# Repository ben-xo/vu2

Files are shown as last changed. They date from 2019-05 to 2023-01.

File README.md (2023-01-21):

Sound Reactive Lights (visualiser!)
===================================

This is a self indulgent project by Ben XO https://github.com/ben-xo

The idea is that you feed line level audio into a pin on an arduino, and you get pretty lights out on a strip of Neopixels (WS2812 or compatible).

License
-------

Copyright Ben XO https://github.com/ben-xo All rights reserved.

THIS PROJECT IS NOT OPEN SOURCE. Whilst I have put the source code on GitHub, no part of this project is currently released under any open source license.

I reserve all rights and the right to change this license in future.

What does it look like?
=======================

Kinda like this https://www.instagram.com/p/Bt-8dVqlZSi/ or this https://www.instagram.com/p/Bt-8dVqlZSi/

Features
========

* Works from line-in
* Interrupt driven audio sampling - even with WS2812s (requires a slightly modified FastLED library at https://github.com/ben-xo/FastLED)
* A solid 180 frame per second with 60 WS2812s (or 125fps with 100 WS2812s) with no slow frames or dropped samples
* Beat detection and tempo estimation in realtime. Yep! All on a single Arduino
* 8 cool sound-reactive visualisers. These have been endlessly tinkered with so that they look okay at a range of input volumes and aren't TOO jarring when they change
* Automatic mode changing after a certain number of beats
* Effects work well for a range of music from house and techno to drum & bass
* Visualisers cope with things like DC Offset on the line-in
* push button to change modes
* Status LEDs driven using interrupt driven PWM (so no need for resistors on the status LEDs)
* Screensaver when the audio goes quiet. Because why not!
* Nice rainbow when you turn it on

How to use
==========

Circuit
-------

First of all this should go without saying but LEAVE THE POWER DISCONNECTED until you're ready

You should load up config.h as that's where the pins are assigned - and double check these instructions against it.

Also, I refuse to draw an ASCII diagram so you'll have to interpret my words.

Audio Input
-----------

The audio input stage expects "0" to be at around 2.5v (i.e the mid range of the analog input).

Minimum would be something like:
* ground of audio connected to ground of arduino
* signal (left or right audio channel) connected to A0 through a 3.3uF electrolytic cap
* signal connected to ground via a 103 cap
* signal connected to ground and +5v through 100k resistors (to create a potential divider to get the signal to sit at 2.5v)

That's it.

Output LEDs
-----------

* connect 4 LEDs from D8, D9, D10, and D11 to ground A, B, G and F on a 7-segment. These will show the mode and other things.
  (if you don't have a 7-seg, any LEDs will do). No resistors needed

  Note that quite a lot of stuff is configurable in the config.h BUT THESE ARE NOT because we rely on them being in the half of PORTB.

* connect 2 LEDs from A1 and A2 to ground. These flash in time for the beats. I would connect them to the 7 seg in 2 of the unused positions
  (I use the decimal point, and the low bar.) 

* Configure to other pins if you want, avoid PORTB

Mode Button
-----------

* Pull D7 to ground through a 10k resistor. (if you don't and it floats the mode will go haywire)
* Connect a push button from D7 to pull up to 5v. That's it
* Configure to another pin if you want, but avoid PORTB

LED light strip
---------------

Connect some WS2812s or whatever through a 330 resistor to D6, in "the usual way".

Notes on Power
--------------

Powering an Arduino and lights safely / effectively is a dark art.

Choose a PSU you trust. For 1 Arduino and 2x strips of 60 NeoPixels you probably don't need more than a 2A supply because we're never going to be turning all the lights on full white and leaving them on full white. See https://learn.adafruit.com/adafruit-neopixel-uberguide/powering-neopixels for TMI about how to calculate power usage.

You can wire a 5v supply directly to the 5v pins on the Arduino, but if you do that, you bypass the fuses on the Arduino and if your PSU turns out to be untrustworthy you may end up needing to buy a new Arduino.

You can power the Arduino and lights separately, but if you do, you must connect the GND pins together.

You'll know if you don't have enough power because the thing will keep rebooting (you get a nice rainbow every time it starts up)

Debug monitoring
----------------

If you wanna watch the frame rate (and time taken to do various stages in the main loop) on an oscilloscope, you can hook an oscilloscope to pins D2 and D3. You may need to add a resistor to pull them to GND, or 5v… or you might not need to do either!

If it's working correctly when you zoom in you should see 150Hz on D3 and "other stuff" on D2 which shows phases of the draw and render. (If you want to see the sample rate specifically, you'll need to comment out the usages of DEBUG_SAMPLE_RATE_PIN and uncomment the ones in sampler.h)

Software
--------

***Very important: you need to build against a custom branch of FastLED!***

1) Set up Arduino Studio (or arduino-cli)
2) Install FastLED lib
3) REPLACE FastLED lib with the version from https://github.com/ben-xo/FastLED . My version has modifications to enable interrupts in certain places in order to not drop samples.
4) Make sure the modified FastLED is checked out to the branch `feature/ben-xo-integration-branch`
5) Load vu3.ino into Arduino Studio
6) edit config.h . set your strip length. maybe comment out the DEBUG defines if i left them uncommented
7) program the arduino over USB. (or use ./build-and-upload.sh if you went with arduino-cli)

*N.B* You may want to upgrade avr-gcc to version 11. Setting this up is out of scope of the README. 

Rough instructions for that:
* `brew install arduino-cli`
* `brew tap osx-cross/avr`
* `brew install avr-gcc@11`
* `brew link avr-gcc@11`
* modify `~/Library/Arduino15/packages/arduino/hardware/avr/1.8.3/platform.txt` - change `compiler.path` to `/usr/local/bin/`
* use `./build-and-upload.sh` instead of Arduio Studio to program the chip

Finally
-------

Plug the audio in. Plug the power in. Adjust the volume...

Push button to change modes.
Long press to reset to auto change.
Long long press to reboot.
Double click and triple click get you to an animated test mode and a static test mode. (I think)

There is a screensaver which kicks in after 15 seconds silence, but when there's a signal it is back to VU. You might need to adjust the levels low or high! Sensitivity CAN be adjusted with care in sampler.cpp (adjust "scale" in sampler.cpp), or with resistors etc.

Tips
====

Mac owners can make open Audio MIDI Setup to create a virtual soundcard that combines both the speakers AND the line-out, so that you can play audio out loud AND into the lights simultaneously. Neat trick

Enhancements
============

* You can attach LEDs (output, LED to GND) to the LED pins mentioned in config.h. They will show a binary of which mode is currently in effect. (They're even properly PWM'd so you don't need to attach resistors, like the lazy builder you always wanted to be!)
* if you hold down the button at start up it will enter test mode and the LEDs will be a simple level meter so you can test it before attaching. the Neopixel strip
* The output from the lights pin can drive two strips with the same data so you could put them back to back to make a VU twice as long reflected in the middle!

About The Software
==================

Whilst this project has evolved (slowly) from some sketches I found online, the current code is entirely my own work.

How It Works
------------

This is "what can I squeeze out of an Arduino" project the architecture is quite Arduino specific and heavily timer interrupt driven.

The main loop does does the following:
* processes all samples queued up in the sample buffer to calculate a rolling VU, DC offset and beat detection filter
* stores sample-accurate "beat" information, and recalculates the estimates tempo (which looks a lot better for drum & bass than just the kick detection on its own)
* renders a frame of visualiser
* outputs the LEDs using FastLED

Meanwhile, there are very fast interrupt handlers for sampling the audio, doing PWM on the status LEDs, and maintaining an accurate FPS.

Want to work on it?
-------------------

Yeah! You do! I have no idea what to tell you, ask me questions on Twitter @benxo I have loads of ideas and none of them are important.

Thanks for coming to my TED talk

History
=======

* Worked on it throughout 2017 to 2022
* Made it public in a fit of GitHub and Twitter dopamine-seeking on 11th June 2020
* Made it all-in-one with no second arduino required for beat detect and very fast 180fps Jan 2021

Thanks
======

Have fun and no you can't use it commercially

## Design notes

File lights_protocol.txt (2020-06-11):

/*
 * Copyright Ben XO https://github.com/ben-xo All rights reserved.
 */

lights protocol

SYNC
audio byte full 8
audio byte beat_pass 8
beat_1 bit 1 / beat_2 bit 1 / mode select 6? (0-63?)
address 5? (0-31? - this matches RS-482)
command - 

Sync frame (1) SYNC 
11111000: 

audio frame (2) AAA1 AAA2
DDDDDDDD: audio byte full
DDDDDDBB: BB 00: no beats, no low pass. DD: timestamp? phase? bpm?
          BB 10: beat 2, no low pass. 	DD:			
          BB 01 DD ??????: beat 1 followed by low pass 6-bit
          BB 11 DD ??????: beat 1 and beat 2 followed by low pass 6-bit

Address frame (1) AIxx or AGxx (individual or group)
0000GGGG: G=group address for command (0= everyone, 1-15 specific)
001AAAAA: A=individual address for command (0-31 specific)
01??????:
1???????: reserved. 1111010 is SYNC - do not use

Command frame (1) CFxx
0MMMMMMM: Mode change (128 modes)
1000000D: D=direction (0-1)
1000001P: P=pixel offset (0 = -1, 1 = +1)
100001BB: B=brightness (0-3 = 0 = off, 1 = halve, 2 = double, 3 = full)
10001HHH: H=phase (0-15)
1001SSSS: S=scale audio (0-15)
101DGGGG: D=0 - leave group G. D=1 join group G
110CCCCC: C=color-offset (-16 - -1, then +1 - +16) (no 0 - no point)
1110????: reserved
11110???: reserved
111110FF: SYNC data header F=frame number (0-3)
11111100: ENDD end data frame
11111101: reserved
11111110: reserved
11111111: REND RENDER

8+8+8+8+8 = 50 bits (start + stop) = 125,000 baud rate per sample with no overhead 

space for 80 bytes between samples, but don't want to do that when it's rendering strip
8000us / 8ms per frame at 125fps 
400 us per sample at 2500kHz
= 20 samples per frame 
5us per byte at 200kbps
80 bytes between samples max

~2000 us for 60 pixels
~3300 us for 100 pixels
~5000 us for 150 pixels
~6600 us for 200 pixels

MICROS_PER_SAMPLE = (1000000/SAMPLE_RATE)
MICROS_PER_FRAME = (STRIP_LENGTH*33)
SAMPLES_PER_FRAME = (SAMPLE_RATE/FPS)
SAMPLES_DURING_RENDER = ceil(MICROS_PER_FRAME / MICROS_PER_SAMPLE)

(total frames = FPS)

SYNC [f1 - f<SAMPLES_DURING_RENDER>]
AAA1
AAA2

[x SAMPLES_DURING_RENDER] - 
  5 at 60 pixels
  9 at 100 pixels
  13 at 120 
  15 at 180 pixels 
  16 at 193 pixels - THIS IS MAX
  17 at 200 pixels - NOT ENOUGH SPACE FOR DATA

df1
AAA1 [f<SAMPLES_DURING_RENDER+1>]
AAA2 [78 remain]
SYND 11111000 [77]
AFxx 
CFxx set groupings x 32 32*2 [13]
ENDD [12]

df2 [f<SAMPLES_DURING_RENDER+2>]
AAA1
AAA2 [78 remain]
SYND 11111001
AGxx
CFxx
CFxx
CFxx send command to group * 16 (16*4) [13]
ENDD

df3 [f<SAMPLES_DURING_RENDER+3>]
AAA1
AAA2 [78 remain]
SYND 11111010
AGxx
CFxx
CFxx
CFxx send command to group * 16 (16*4) [13]
ENDD

AAA1 [f<SAMPLES_DURING_RENDER+4> - f<FPS-1>]
AAA2

df4
AAA1 [f<FPS>]
AAA2 [78 remain]
SYND 11111011
REND

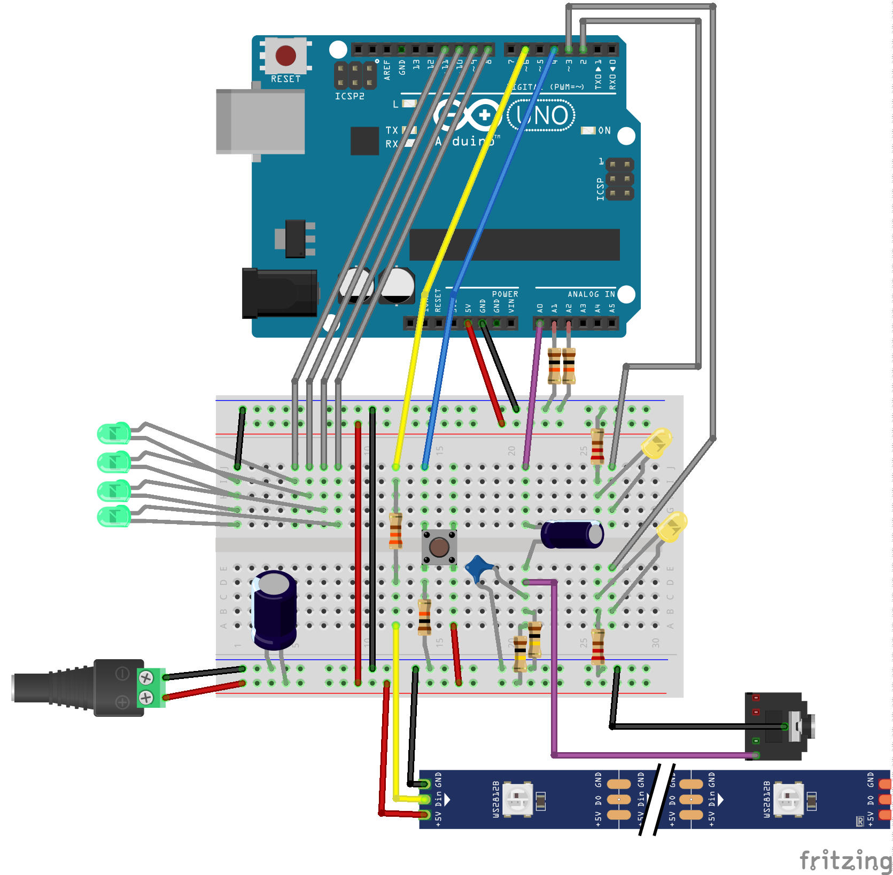
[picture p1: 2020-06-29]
vu2 advanced.png

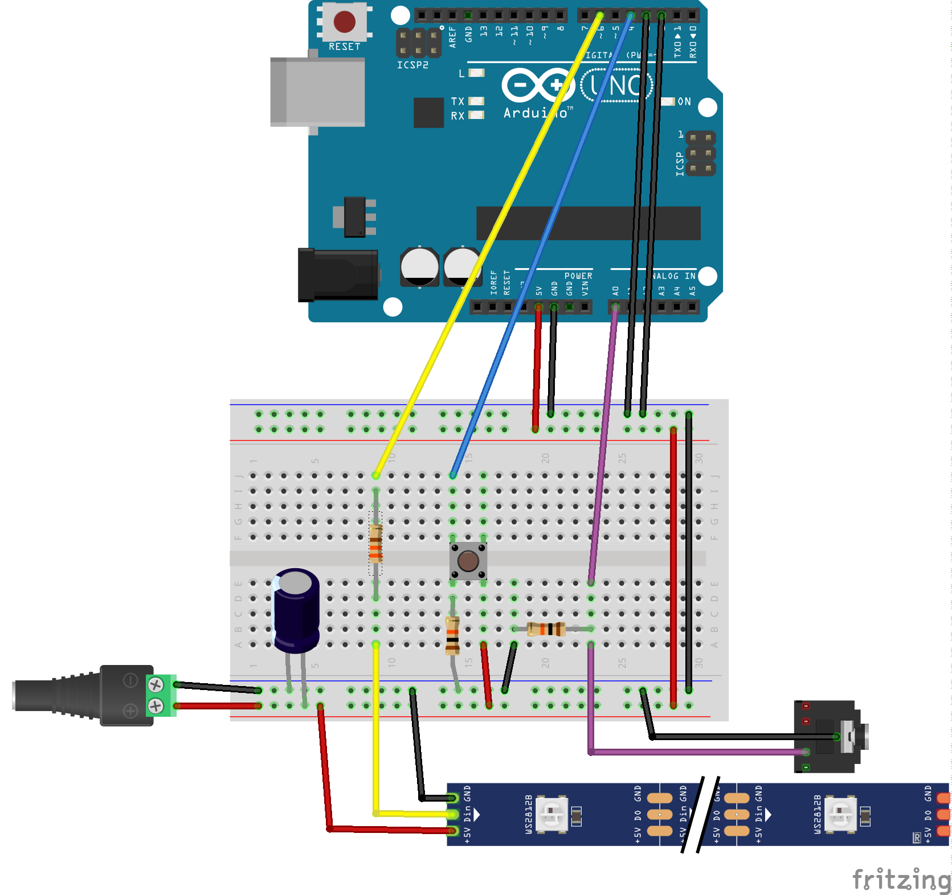
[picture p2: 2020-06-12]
vu2 basic.png

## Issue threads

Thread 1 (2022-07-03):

Documentation in Readme is out of date

ichttt, 2022-07-03:
Readme states that button pin is D4 by default, but in the latest version it is D7.
Also, I can't figure out how to adjust the sensitivity in sampler.cpp (as outlined by the readme).
It would also be helpful if you could tell which arduino you have been using for this. I have a feeling that my uno has not enough power to handle all the computations in (can't test though since I don't have an oscilloscope).
Cause this looks like a awesome project if I could get it to work properly

ben-xo, 2022-09-09:
Hi There! I'm so sorry I only just saw this. You're the first person to ask!!

I'll see what I can do with the doc, and give you some guidance - feel free to contact me more directly (@benxo on Twitter or ben-xo on Reddit if you want) or we can discuss here - but I seem to miss notifications a lot here!

ben-xo, 2022-09-09:
I am using an Arduino Nano (16MHz AVR) - it won't work with a non-AVR Arduino because this is very much a project i've done for myself, not that it should be hard to get working, and i'd love to help you out.

ben-xo, 2022-09-09:
Hopefully #2 will help a bit? Can also share some pictures if you like>

ichttt, 2022-09-11:
Hi, yeah I've kinda given up on using beat detection and just build some other cool effects with my neostrip. But thanks anyway!
The documentation improvements look good, hopefully it well help some future persons that are trying to build something like this.

Closed 2022-09-11.

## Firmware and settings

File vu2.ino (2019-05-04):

#include "config.h"

#include "ledpwm.h"
#include "render.h"
#include "ultrafastneopixel.h"
#include "sampler.h"
#include "debugrender.h"

UltraFastNeoPixel strip = UltraFastNeoPixel(STRIP_LENGTH);

uint32_t static start_time; // time each loop started.
uint32_t static silent_since; // time we've been silent since.
bool static slow = false; // track render time

#define SHORT_PUSH 1
#define LONG_PUSH 2

void setup() {
  // put your setup code here, to run once:

  // the pin with the push button
  pinMode(BUTTON_PIN, INPUT);
  pinMode(BEAT_PIN_1, INPUT);
  pinMode(BEAT_PIN_2, INPUT);
  pinMode(NEOPIXEL_PIN, OUTPUT);
  pinMode(DUTY_CYCLE_LED, OUTPUT);
  
  // the pin with the push-button LED
  pinMode(BUTTON_LED_PIN,OUTPUT);  

  // the pin with the mode display
  pinMode(MODE_LED_PIN_1,OUTPUT);
  pinMode(MODE_LED_PIN_2,OUTPUT);
  pinMode(MODE_LED_PIN_3,OUTPUT);
  pinMode(MODE_LED_PIN_4,OUTPUT);

//  setup_filter();
  setup_render();
  setup_sampler();
  setup_ledpwm();
//  Serial.begin(2000000);
//  randomSeed(analogRead(2));
}

static uint8_t calculate_vu(uint8_t sample_ptr) {
  // VU is always width of last 20 samples, wherever we happen to be right now.
  uint8_t max_val=0, min_val=255;
  for (uint8_t i = 0; i < VU_LOOKBEHIND; i++) {
    uint8_t int_sample = samples[(sample_ptr-i)%SAMP_BUFF_LEN];
    if(int_sample > max_val) max_val = int_sample;
    if(int_sample < min_val) min_val = int_sample;
  }
  return max_val - min_val;
}

#ifdef FRAME_RATE_LIMIT
static void reach_target_fps() {
  uint32_t end_time = micros();
  uint32_t total_time;
  if (end_time < start_time) {
    total_time = -end_time + start_time;
  } else {
    total_time = end_time - start_time;
  }
  
  // frame target is 100fps, or 20k microseconds
  if(total_time > 5000) {
    slow=true;
  } else {
    delayMicroseconds(5000-total_time);
    slow=false;
  }
  start_time = end_time;
}
#endif

// returns true on the falling edge of a button push
static uint8_t was_button_pressed(uint8_t pins) {
  static bool is_down = false;
  static uint32_t last_push;
  if(is_down && !pins) {
    is_down = false;
    if(millis() - last_push > 3000) {
      // long push
      return LONG_PUSH;
    }
    // short push
    return SHORT_PUSH;
  }
  if(!is_down && pins) {
    is_down = true;
    last_push = millis();
  }
  // no push yet, although one may be in progress.
  return 0;
}


// auto change every 8 bars
uint32_t static last_beat;
byte static beat_count = 0;
static bool auto_mode_change(bool is_beat) {
  if(!is_beat) return false;
  uint32_t now = millis();
  if(now - last_beat > AUTO_BEATS_SILENCE_THRESH) {
    // mode change anyway if this is the first beat in ages
    last_beat = now;
    beat_count = 0;
    return true;
  }
  if(now - last_beat > AUTO_BEATS_MIN_THRESH) {
    last_beat = now;
    beat_count++;
    if(beat_count >= AUTO_BEATS) {
      beat_count = 0;
      return true;
    }
  }
  return false;
}

void debug_loop() {
  byte is_beats = 0;
  bool is_beat_1;
  bool is_beat_2;
  uint8_t vu_width = 0;
  uint8_t mode = 0;

  start_time = micros();
  silent_since = start_time;
  while(true) {
    start_time = micros();
    
    // read these as they're volatile
    cli();
    uint8_t sample_ptr = current_sample;
    sei();

    uint8_t pushed = was_button_pressed(PIND & (1 << BUTTON_PIN));
    if(pushed == SHORT_PUSH) {
      mode++;
      if(mode > MAX_MODE) {
        mode = 0;
      }
    }
    
    is_beats = PIND & ((1 << BEAT_PIN_1) | (1 << BEAT_PIN_2)); // read once - port is volatile
    vu_width = calculate_vu(sample_ptr);
      
    is_beat_1 = is_beats & (1 << BEAT_PIN_1);
    is_beat_2 = is_beats & (1 << BEAT_PIN_2);

    switch(mode) {
      case 0: // show that beats are working
        PORTB = (is_beat_1 << 1) | (is_beat_2 << 2);
        break;
      case 1: // show that sampling is working
        PORTB = 0;
        if (vu_width > 128) PORTB |= 32;
        if (vu_width > 64)  PORTB |= 16;
        if (vu_width > 32)  PORTB |= 8;
        if (vu_width > 16)  PORTB |= 4;
        if (vu_width > 8)   PORTB |= 2;
        break;
    }

    debug_render_combo(is_beat_2, is_beat_1, current_sample);

    strip.show();
  }  
}

void loop() {
  // put your main code here, to run repeatedly:

  // hold down button at startup
  if(PIND & (1 << BUTTON_PIN)) {
    debug_loop();
  }
  
  byte is_beats = 0;
  bool is_beat_1 = false;
  bool is_beat_2 = false;
  uint8_t vu_width = 0;
  uint8_t mode = 0;
  uint8_t last_mode = 0;
  bool auto_mode = true;
  bool is_silent = false;
  bool is_attract_mode = false;

  do_banner();

  silent_since = micros();
  while(true) {
    start_time = micros();
    
    // read these as they're volatile
    uint8_t sample_ptr = current_sample;
    uint8_t pushed = was_button_pressed(PIND & (1 << BUTTON_PIN));
    
    if(pushed == SHORT_PUSH) {
      mode++;
      auto_mode = false;
      is_attract_mode = false;
      if(mode > MAX_MODE) mode = 0;
    } else if(pushed == LONG_PUSH) {
      auto_mode = true;
      mode = 0;
    }

    if(pushed) {
      portb_val = (mode << 1); // writes directly to pins 9-12
    }
    
    is_beats = PIND & ((1 << BEAT_PIN_1) | (1 << BEAT_PIN_2)); // read once - port is volatile
    vu_width = calculate_vu(sample_ptr);

    if (pushed || vu_width > ATTRACT_MODE_THRESHOLD) {
      // loudness: cancel attract mode, and so does a button press.
      is_silent = false;
      is_attract_mode = false;
    } else {
      // quiet: short or long?
      if(!is_silent) {
        // first loop of silence. Record time.
        silent_since = start_time; // note start time of silence
        is_silent = true;
      } else {
        // 2nd+ loop of silence. Long enough for attract mode?
        if (!is_attract_mode && ((start_time - silent_since)/1024 > ATTRACT_MODE_TIMEOUT)) {
          is_attract_mode = true;
        }
      }
    }

    if(is_attract_mode) {
      render_attract();
    } else {
      
      is_beat_1 = is_beats & (1 << BEAT_PIN_1);
      is_beat_2 = is_beats & (1 << BEAT_PIN_2);
      if(auto_mode && auto_mode_change(is_beat_1)) {
        last_mode = mode;
        while(mode == last_mode) mode = random(0,MAX_MODE+1); // max is exclusive
        PORTB = (mode << 1); // writes directly to pins 9-12.
      }

      render(vu_width, is_beat_2, true, mode, is_beat_1, current_sample);
    }

    strip.show();

#ifdef FRAME_RATE_LIMIT
    reach_target_fps();
#endif
  }
}

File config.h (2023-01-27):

/*
 * Copyright Ben XO https://github.com/ben-xo All rights reserved.
 */

#ifndef _CONFIG_H
#define _CONFIG_H

/*** whether to display a rainbow at startup ***/
// #define DO_BANNER 1
#define DO_BANNER 0

/*** Pin configuration ***/
#define AUDIO_INPUT_PIN 0
#define DEBUG_FRAME_RATE_PIN A3
#define DEBUG_SAMPLE_RATE_PIN A4
#define DEBUG_AUDIO_PROCESSING_RATE_PIN A5
#define NEOPIXEL_PIN 6
#define BUTTON_PIN 7
#define MODE_LED_PIN_1 8
#define MODE_LED_PIN_2 9
#define MODE_LED_PIN_3 10 
#define MODE_LED_PIN_4 11
#define MODE_LED_PIN_5 12
#define BUTTON_LED_PIN 13

/*** Optional beat detection using interrupts (would require a bit of a rework of the main ino) ***/
//#define BEAT_WITH_INTERRUPTS 1
#define BEAT_PIN_1 A1 // must be an interrupt pin e.g. 2 if BEAT_WITH_INTERRUPTS is 1
#define BEAT_PIN_2 A2 // must be an interrupt pin e.g. 3 if BEAT_WITH_INTERRUPTS is 1

/*** LED PWM configuration ***/
#define PWM_LED_FRQ      10000 // 10kHz
#define PWM_DUTY_PERCENT 5

/*** If you connect A, B, G and F of a 7 segment display to PORTB (that is, D8-D11) then you can have a cute shape instead of a binary counter ***/
#define SEVEN_SEG_MODE_DISPLAY 1


/*** Neopixel configuration ***/
#define STRIP_LENGTH 100 // don't recommend >100
#define FPS 150 // you can get up to about 180fps with a 60 strip, 125 with a 100-strip
#define FRAME_LENGTH_MICROS (1000000 / FPS) // 8000us
#define FRAME_LENGTH_MILLIS (1000 / FPS) // 8000us
#define FRAME_LENGTH_CYCLES (F_CPU / FPS)   // 128000 @ 16MHz
#define FRAME_RATE_LIMIT 1 // limitless is fun!

/*** Audio sampling config ***/
#define SAMP_BUFF_LEN 128 // this needs to be a power of 2.
#define SAMP_FREQ 5000 // Hz

/*** Beat Detect config ***/
#define AUTO_BEATS 128 // beats before change
#define AUTO_BEATS_MIN_THRESH 300 // ms
#define AUTO_BEATS_SILENCE_THRESH 5000 // ms
//#define BEAT_SUSTAIN 40 // minimum length of a beat detection



// This awkward calculation is to get it to round to nearest number of frames, which is roughly 4 frames at 125fps
// See https://stackoverflow.com/a/2422722. 
#define BEAT_FLASH_LENGTH ((30 + (1000/FPS) - 1) / (1000/FPS)) // frames
#define MIN_BPM_FRAMES ((FPS*60)/85) // frames per beat @ ~85bpm


/*** Attract mode config ***/
#define ATTRACT_MODE_THRESHOLD 24 // vu value
#define ATTRACT_MODE_TIMEOUT 15000 // ms (although this is compared 1024)
#define ATTRACT_MODE_DOTS 5

/**** Minimum Power Draw for USB battery packs ***/
#define BRIGHTNESS_TO_MA_RATIO 5 // from https://www.temposlighting.com/guides/power-any-ws2812b-setup
#define MINIMUM_POWER_DRAW 200 // mA - guess based on https://www.audiosciencereview.com/forum/index.php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

// By default it uses an entire frame's worth of samples, i.e everything not yet included in a VU.
// But you can override that to suit your taste, especially as upping the FPS would reduce the number of samples in the calculation.
//#define VU_LOOKBEHIND 20


/*** random debug stuff ***/
//#define DEBUG_ONLY 1
//#define LONGCLI 1

// Tries to boost the volume to get a better effects on a lower signal. Surprisingly effective.
// Larger numbers have a larger decay. 0 deactivates.
#define AUTOGAIN 12

#endif /* _CONFIG_H */

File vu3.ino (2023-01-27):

/*
 * Copyright Ben XO https://github.com/ben-xo All rights reserved.
 */

// this define is for FastLED
#define NO_CLOCK_CORRECTION 1
#define FASTLED_ALLOW_INTERRUPTS 1
#define NO_MINIMUM_WAIT 1
// #define TRINKET_SCALE 0


#include "config.h"

#include "sampler.h"
#include "ledpwm.h"
#include "tempo.h"

#include "sevenseg.h"
#include "framestate.h"

#include "loop.h"
bool filter_beat = false;
uint8_t my_current_sample = 0;
uint16_t my_sample_sum = 0;

#ifdef BEAT_WITH_INTERRUPTS
// This mode doesn't currently work, because it's all been integrated into this project and isn't needed
// If you want to trigger the beats with interrupts, you'll need to reconfigure the BEAT_PIN_1 and 2 to inputs
// and take out the IIR filter etc down below.
#include "beatdetect.h"
volatile uint8_t beats_from_interrupt = 0;
#endif

#include "buttons.h"
#include "hardreset.h"
#include "fps.h"
#include "demo.h"

#include <DigitalIO.h>

#include "debugrender.h"
#include "render.h"

CRGB leds[STRIP_LENGTH];
extern struct Framestate F;

void setup() {
  // put your setup code here, to run once:

  // the pin with the push button
  pinMode(NEOPIXEL_PIN, OUTPUT);

  beat_pin.config(OUTPUT, LOW);
  tempo_pin.config(OUTPUT, LOW);
  button_pin.config(INPUT, LOW);
  
  // the pin with the push-button LED
  pinMode(BUTTON_LED_PIN,OUTPUT);  

  // the pin with the mode display
  pinMode(MODE_LED_PIN_1,OUTPUT);
  pinMode(MODE_LED_PIN_2,OUTPUT);
  pinMode(MODE_LED_PIN_3,OUTPUT);
  pinMode(MODE_LED_PIN_4,OUTPUT);
  pinMode(MODE_LED_PIN_5,OUTPUT);
  pinMode(BUTTON_LED_PIN,OUTPUT);
  
  FastLED.addLeds<NEOPIXEL, NEOPIXEL_PIN>(leds, STRIP_LENGTH).setCorrection(TypicalLEDStrip);

  FastLED.setDither( 0 );
  
  setup_render();
  setup_sampler(SAMPLER_TIMER_COUNTER_FOR(SAMP_FREQ));
  setup_tempo();
  setup_fps();
  setup_ledpwm();
  setup_debug();

#ifdef BEAT_WITH_INTERRUPTS
  setup_beatdetect();
#endif

  setup_initial_framestate();

  setup_demo();

}

// auto change every 8 bars
static bool auto_mode_change(bool is_beat) {
  uint16_t static last_beat;
  byte static beat_count = 0;
  if(!is_beat) return false;
  uint16_t now = (uint16_t)millis();
  if(now - last_beat > AUTO_BEATS_SILENCE_THRESH) {
    // mode change anyway if this is the first beat in ages
    last_beat = now;
    beat_count = 0;
    return true;
  }
  if(now - last_beat > AUTO_BEATS_MIN_THRESH) {
    last_beat = now;
    beat_count++;
    if(beat_count >= AUTO_BEATS) {
      beat_count = 0;
      return true;
    }
  }
  return false;
}

static const uint8_t masks[16] = { 
  0b11111110, 0b11111110, 0b11111110, 0b11111110,
  0b11111110, 0b11111110, 0b11111110, 0b11101110,
  0b10101010, 0b10101010, 0b10001000, 0b10001000,
  0b10000000, 0b10000000, 0b10001000, 0b10101010
};

// there are only 4 lights, so 5 brightness levels
static const uint8_t vals[16] = { 
  0b00000000, 0b00000000, 0b00000000, 0b00000000,
  0b00000000, 0b00000000, 0b00000000, 0b00000000,
  0b00000000, 0b00000000, 0b00000000, 0b00000000,
  0b00000000, 0b11110000, 0b11110000, 0b11110000
};

/*
 * Mess with the brightness of the status LEDs (by adjusting the mask and double-buffer content) 
 * so that it's VU reactive. Kinda ugly but also kinda cool at the same time.
 */
static void ledpwm_vu_1() {

    // uint8_t volatile old_portb_val = portb_val;
    
    uint8_t four_bit_level = F.vu_width / 4;
    if(four_bit_level > 15) four_bit_level = 15;
    uint8_t new_portb_mask = masks[four_bit_level];

    // uint8_t three_bit_level = (four_bit_level >> 1) & 0b00000111;
    // uint8_t new_portb_val = (old_portb_val & 0x0F) | vals[three_bit_level];
    uint8_t new_portb_val = vals[four_bit_level] | seven_seg(F.mode);

    set_status_leds_and_mask_rotate(new_portb_val, new_portb_mask);
}

void loop() {
  // put your main code here, to run repeatedly:

  // hold down button at startup
  if(button_pin.read()) {
    demo_loop();
  }
  
  F.is_beat_1 = false;
  F.is_beat_2 = false;
  F.vu_width = 0;
  F.mode = 0;
  F.last_mode = 0;
  F.is_new_mode = true;
  F.auto_mode = true;
  F.is_silent = false;
  F.is_attract_mode = false;
  F.pushed = false;

#if DO_BANNER
  do_banner();
#endif

  set_status_leds(seven_seg(F.mode));

  while(true) {

    one_frame_sample_handler();
    ledpwm_vu_1();

    if(F.is_attract_mode) {
      render_attract();
    } else {
      
      if(F.auto_mode && auto_mode_change(F.is_beat_1)) {
        F.last_mode = F.mode;
        while(F.mode == F.last_mode) F.mode = random8(MAX_MODE+1); // max is exclusive
        // the mode indicator LED is changed by ledpwm_vu_1() below
        F.is_new_mode = true;
      }

      render(my_current_sample, my_sample_sum);
    }

    DEBUG_SAMPLE_RATE_HIGH();

    FastLED.show();
    //FastLED[0].show(&leds[0], STRIP_LENGTH, 255);

    // do post-frame-render stuff
    uint8_t pushed = was_button_pressed();
    F.pushed = (bool)pushed;
    switch(pushed)
    {
      case SINGLE_CLICK:
        // change mode (cancels auto change)
        F.auto_mode = false;
        F.is_attract_mode = false;
        F.mode++;
        if(F.mode > MAX_MODE) F.mode = 0;
        set_status_leds(seven_seg(F.mode));
        F.is_new_mode = true;
        break;

      case LONG_PUSH:
      case DOUBLE_CLICK:
        // reinstate auto change
        F.auto_mode = true;
        F.is_attract_mode = false;
        F.mode = 0;
        set_status_leds(seven_seg(F.mode));
        F.is_new_mode = true;
        break;

      case TRIPLE_CLICK:
        clear_status_leds();
        demo_loop();
        clear_status_leds();
        F.is_new_mode = true;
        break;

      case QUADRUPLE_CLICK:
        clear_status_leds();
        sober_loop();
        clear_status_leds();
        F.is_new_mode = true;
        break;

      case REALLY_LONG_PUSH:
        hard_reset(); // this never returns
        break;

      default:
        break;
    }

    frame_epilogue();
  }
}

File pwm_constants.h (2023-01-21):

/*
 * Copyright Ben XO https://github.com/ben-xo All rights reserved.
 */

#ifndef _PWM_CONSTANTS_H
#define _PWM_CONSTANTS_H

#include <Arduino.h>
#include "config.h"

// 0b11111111 is "invisible" and 0b00000000 is "super bright" not that the human eye can tell
#ifndef MASK_RESET_VAL
#  define MASK_RESET_VAL 0b01111111
#endif

// These values are specific to the LEDs you choose. 
// Override them in config.h if you like.

#ifndef PWM_LED_FRQ
#  define PWM_LED_FRQ 10000 // 10kHz
#endif

#ifndef PWM_DUTY_PERCENT
#  define PWM_DUTY_PERCENT 10
#endif

#define PWM_PRESCALER 8 // must match what enable_ledpwm() does

// e.g. at 16MHz, overflow val will be 200. At 20Mhz, 250. At 8MHz, 100.
#define PWM_OVERFLOW_VALUE (F_CPU / PWM_LED_FRQ / PWM_PRESCALER)

// e.g. at 16MHz and 10% duty, this will be 180. At 20Mhz, 225. At 8MHz, 90.
#define PWM_DUTY_VALUE     (PWM_OVERFLOW_VALUE - (PWM_OVERFLOW_VALUE / (100 / PWM_DUTY_PERCENT)))

// starts the timer at an offset so that PWM interrupts don't coincide with other interrupts.
// offset should not be between PWM_DUTY_VALUE and PWM_OVERFLOW_VALUE, and preferably quite far from them
#define PWM_STARTING_OFFSET (PWM_DUTY_VALUE / 2)

/* definition to expand macro then apply to pragma message */
/* from https://stackoverflow.com/questions/1562074/how-do-i-show-the-value-of-a-define-at-compile-time */
#define VALUE_TO_STRING(x) #x
#define VALUE(x) VALUE_TO_STRING(x)
#define VAR_NAME_VALUE(var) #var "="  VALUE(var)

// compile time debug to see the PWM vals
#pragma message(VAR_NAME_VALUE(PWM_OVERFLOW_VALUE))
#pragma message(VAR_NAME_VALUE(PWM_DUTY_VALUE))

#endif /* _PWM_CONSTANTS_H */

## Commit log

2018-11-04 First commit. refactoring the VU meter code so that I can make the sampling interrupt based.
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2018-11-18 Get the ADC working, and use smaller instruction footprint for the pixels.
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2018-11-18 These are good debug settings, as you get 3 different coloured sample periods on the strip (at 1x, 3x and 5x period).
2018-11-22 A whole bunch of type changes, plus some optimisation fiddling on the ADC interrupt.
2018-11-24 Disable timer0 interrupt (used for delay() and millis()) to reduce sampling jitter.
    Is this necessary? Probably not!
    [sampler.cpp]
2018-11-24 Only need interrupts disabled on 0-bits for ultrafastneopixel.cpp
2018-11-24 Do the 0/1 detection from the sampler (noise floor) when rendering, to keep the interrupt short.
    [sampler.cpp, vu2.ino]
2018-11-25 Use internal ref voltage - gives brighter pixels / larger range. Maybe should be configurable.
2018-11-25 Add shortcli() and longcli() helpers for debugging interrupt problems.
    [config.h]
2018-11-25 Don't disable timer; and get assmbler code (that I'm not using) working
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2018-11-25 Do all the sampling using TIMER1, so it can be exactly 5kHz with minimal jitter
    [sampler.cpp]
2019-01-06 Fix tthe weird glitch with red pixel! PASSING OBJECTS
    [config.h, sampler.cpp, vu2.ino]
2019-01-06 Fix strip externing global, and also finally render the original modes!!
    [render.cpp, vu2.ino]
2019-01-06 Fine tune sparkles for max volume. Never light more than half the lights at once as that doesn't sparkle!
    [render.cpp]
2019-01-06 Loads of fixes to modes. Just that pesky beat line now
    [render.cpp, sampler.cpp, vu2.ino]
2019-01-06 New beat line phase line with reversing on beat
    [render.cpp]
2019-01-27 Swap pins for beat input, for the PCB
    [config.h]
2019-01-27 Fix render_shoot_pixels glitch, and make bar segments faster / less RAM
    [render.cpp]
2019-01-27 Attract mode doesn't work - but resetting to auto mode does.
    [config.h, render.cpp, vu2.ino]
2019-02-01 Change button definition for pins to match hardware
2019-02-03 Remove filter files which are in the beat detect project now
2019-02-04 Fix attract mode combination
    [render.cpp, vu2.ino]
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2019-02-15 Fix overflow in bar segments (which should loop) when >64 pixels
    [render.cpp]
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2019-02-15 Fix startup glitch, and make dots collide so their trails don't flip colours
    [render.cpp]
2019-02-24 That mode line looks like a bug to me!
    [vu2.ino]
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2019-05-04 Use PWM on LEDs that dont have resistors
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2019-05-28 Fix beat sustain (needs an off!)
    [vu3.ino]
2019-05-31 Fix banner and attract mode
    [config.h, render.cpp, vu3.ino]
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2019-06-09 Trying to get rid of that beat line glitch. Interrupt less often...?
    [beatdetect.cpp, config.h, ledpwm.cpp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]
2019-07-14 Shave 4 cycles off the PWM interrupt handler by avoiding SREG. It's now about 10 cycles for each edge.
    [ledpwm.cpp]
2019-07-14 Export methods to enable and disable PWM - probably won't need them though.
    [ledpwm.h]
2019-07-14 Add an offset to the LEDPWM so that it doesn't interrupt at the same time as the sampler
    [ledpwm.cpp]
2019-07-14 Add debugging code for the sampler so you can see how long the interrupt takes using an oscilliscope
2019-07-14 I suppose the debug pin should be an output, although weirdly it doesn't really matter because of the pull-up.
    [sampler.cpp]
2019-07-14 Alias both interrupts to the same vector. (The compiled code does NOT optimise well otherwise)
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2019-07-14 Add commented out debug defines for sampling. Enable these to see when the sampler works by spying on a pin
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2019-07-18 Fix framerate limiter. Unfortunately, frames are <1ms so it doesn't have enough resolution!
    [vu3.ino]
2019-07-18 Fix bug with mode light LEDs when it's rolls over
    [vu3.ino]
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2019-07-20 Fixes for sparkles, beat_bounce_flip, plume, and make the VUs faster with FastLED functions
    [config.h, render.cpp, vu3.ino]
2019-07-20 Even out frame rate in lieu of finding the bug
    [vu3.ino]
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2019-07-27 Sampler: fix type of current_sample, and make ADC pin more explicit (to match the code in beat_flash)
    [config.h, sampler.cpp]
2019-07-30 Remove do_fade, remove a pointless cli/sei, localise SILVER/GOLD consts (saves memory), revert shoot_pixels before figuring out how to fix it.
    [render.cpp, vu3.ino]
2020-06-12 Add Fritzing diagram
    [vu2 basic.fzz]
2020-06-29 Fix nasty bug in the VU calculator! would read outside of the sample buffer when the index was <20, which led to nasty flickering.
    [sampler.cpp]
2020-06-29 Remove beat flags from main loop and also activate mode pin 5
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2020-06-29 Fix Beat Line Render for signed samples
    [render.cpp]
2020-06-29 Update Fritzing
    [vu2 advanced.fzz]
2020-07-04 Stabilise framerate by using a timer for the wait loop
    [vu3.ino]
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2020-07-04 Experiment failed. Takes too long, ruins FastLED. Interrupts can only be enabled in FastLED if they're very fast.
    [render.cpp, sampler.cpp, vu3.ino]
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2020-07-04 Fix the weighted averaging
    [sampler.cpp, vu3.ino]
2020-07-05 Save 128 bytes of RAM by halving the unnecessarily large sample buffer, after fixing the alignment and pointer math issues.
    [config.h, sampler.cpp]
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2020-07-17 Tempo detection doesn't work but we can fix it later.
    [vu3.ino]
2020-07-18 Try to get sample-accurate beat information for the beat line, and also fix the bounce flip which needed scaling. Not sure what happened there
    [render.cpp, sampler.cpp, vu3.ino]
2020-12-30 Add a frame counter, to use in tempo calculation. Better than relying on millis.
2020-12-31 Drastically simplify tempo calculator (which should also make it much easier to prove correctness).
    [config.h]
2020-12-31 Fix logic error incrementing flash frames
2020-12-31 Fix tempo pin calculation (was not comparing the right elements of the array)
    [vu3.ino]
2020-12-31 Fix bug where tempo pin stays high sometimes when the BPM drops too low
2020-12-31 Fix tempo estimator failing after the frame counter overflows
2021-01-03 Add a configurable DC_OFFSET (i.e. which value is "0" for the audio) to the config.
    The intention is that the audio range is from -127 to 127, which in unsigned values is 0 to 255. However, due to the nature of electronics, this isn't usually spot on. Some visualisers don't look goo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
    TODO: estimate this at startup? Or use a differential instead of absolute samples?
2021-01-03 adjust samples by the DC_OFFSET for render_combo_samples_with_beat(), otherwise it just looks "very blue".
    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
2021-01-03 Actually... if we do the beat line with sample-to-sample diffs then the DC offset doesn't matter.
    It changes the characteristics a bit but still looks good and copes with DC offset much better.
    [render.cpp]
2021-01-03 Keep a running sum of the sample buffer so that we can calculate a DC offset (as an average of the whole buffer) to use as zero on some effects. This will adapt to noisy environments as well!
    with a sample buffer size of 128 samples at 5kHz this is effectively a low pass filter rolling off under about 40Hz
2021-01-03 Pretend to still support beat_detection with interrupts so it doesn't all look like junk commented out code
    [config.h, vu3.ino]
2021-01-03 filter_beat is no longer volatile external (it's not set in an ISR anymore) so this should help gcc a little bit
    [sampler.cpp, vu3.ino]
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2021-01-03 Add a Framestate object and then use it in the main loop. (No optimisations yet)
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2021-01-03 Fix glitch caused by not using full raneg of phase
    [render.cpp]
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2021-01-04 Add PWM on the beat pins. However because they're on the same PORT as the FastLED strip, we have to do extra work on the interrupt otherwise we get an annoying flickering on the beat pins.
    The solution to this would be either a massive hack of FastLED, or to move the Beat pins to a different port.
2021-01-05 Fast PWM of the beat pins, so you don't need those two extra resistors.
    Adds about 25% to the ISR, but the ISR is already very fast.
2021-01-05 Swapped the beat pins with the debug pins, because FastLED might be interfering with the PWM when it bitbangs the port. (the debug pins only change between frames, so it doesn't matter for them).
    [config.h]
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2021-07-04 move fps_count() into aheader file, so that it can be then attached to a different interrupt if i want.
2021-07-04 Instead of FPS having its own interrupt, add an optimised version to the uptick of ledpwm.
    It probably uses about the same amount of resource as it's called twice as often, but hey.
    The main advantage is that it frees timer1.
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2021-07-12 Interupt combined more efficiently. Way too slow though!?
    [ledpwm.cpp]
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2021-08-01 Experimental direct pointer bashing for frames with two windows so you can do looping and scrolling without actually mopving the pixels around
2021-08-01 yeah so it turns out samples doesn't need to be aligned. RAM SAVER
    [config.h, sampler.cpp]
2021-08-01 remove "slow" var (unused, ram waster) and also improve the noise floor for the screensaver
    [config.h]
2021-08-01 Fix incorrect pixel in startup
    [vu3.ino]
2021-08-01 Turn off clock correction, not color correction
    [vu3.ino]
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2021-08-16 Use some new sample buffer consuming primitives so we do less work in the ISR
2021-08-16 New sampler ISR based on experiments to shave off clock cycles.
    The body of this one is approx 40 cycles instead of 51
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2021-08-16 Speculatively undo some of the Structing in case it was causing the perf drop i'm seeing.
2021-08-16 Wow. Okay, so those sampler methods I made were causing a 25% slowdown on the sampler. No good!
2021-08-16 Do the button push test after the frame is rendered. Carry the state over to the next frame.
2021-08-16 Rearrange the VU for responsiveness. Keep track of its sample buffer position separately.
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2022-01-22 Fix incorrect comment about AREF
    [sampler.cpp]
2022-01-22 UGH fix a stupid int/sign rollover bug in the vu that was causing ALL of the unexplained flicker
    [sampler.cpp]
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2022-06-04 Workaround flaky EMF internet weird arduino-cli bug
2022-06-04 WIP - well, this version of the new button code doesn't do what i want yet but at least it's easier to test
    [config.h, vu3.ino]
2022-06-04 Better way to do a hard reset using the WDR interrupt - otherwise resets use stack
    [vu3.ino]
2022-06-05 Add a "sober mode" - static rainbow lights for less motion / consistent brightness whilst you're stuck in your tent trying to find something
    [vu3.ino]
2022-06-05 Move button state into Framestate, thus saving 1 byte of static ram
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2022-06-19 Refactor first stage of the menu upgrade for demo / sober (renamed demo from debug)
2022-06-19 new menu layout. LONG_PUSH is the most "resetting" push so that's now what that is; exit will be double click as it's simple
    [demo.cpp, vu3.ino]
2022-06-19 This branch, it turns out, is not about minimum power draw, but about nice buttons
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2022-06-29 Refactor debugging stuff, make it work with pullups (attach probe to +5 and data pins)
2022-06-29 add some assembler for a rotating double buffer mask on portb so i can do nice fade in / flashing
2022-06-29 Get the frame counter correct
    [demo.cpp]
2022-06-29 Okay this is going to sound really dumb but I really love beautiful LED fades so here we are
2022-06-29 Refactor ledpwm and fps_count into its own file for separation of concerns
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2022-06-29 correct usage of GPIO flags
    [ledpwm.cpp]
2022-06-29 pwm reset constant
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2023-01-21 Some missed stuff from that aborted fps-count patch
    [ledpwm.cpp]
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2023-01-21 Settled on this LED PWM VU, it's ugly but it works fine.
2023-01-21 Make one LED interrupt 1 cycle quicker… and a lsightly nicer LED VU… and and save a GPIOR0 flag
2023-01-21 Even faster LED buffer swap (7 cycldes, heh)
    [ledpwm.cpp, vu3.ino]
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2023-01-21 Add some notes. I Adjusting PWM width is not going to be a viable strategy because the interrupts are too heavy.
    [ledpwm.cpp]
2023-01-21 Safer PWM_PRESCALER and fix up some dox
    [ledpwm.cpp, pwm_constants.h]
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2023-01-21 Helper methods that set the intial value of the mask correctly
    [ledpwm.h]
2023-01-21 Turns out, pre-swapping doesn't work (yet)
    [ledpwm.h, vu3.ino]
2023-01-21 ledpwm_vu overhaul, add back buffer rotate mode (adds 14 cycles to one of the interrupts, though)
2023-01-27 Use the entry point and heap to avoid another static
    [render.cpp]
2023-01-27 Replace render_sparkles with something nicer and more symmetrical and hypnotic
    [render.cpp]
2023-01-29 Really pretty beat bounce flip mitosis visualiser
    [render.cpp]
2023-02-01 Fix bug where tempo will resume flashing after 7 minutes due to frame counter rollover
